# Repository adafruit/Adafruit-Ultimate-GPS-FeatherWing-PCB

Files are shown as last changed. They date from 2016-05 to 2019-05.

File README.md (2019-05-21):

## Adafruit Ultimate GPS FeatherWing PCB
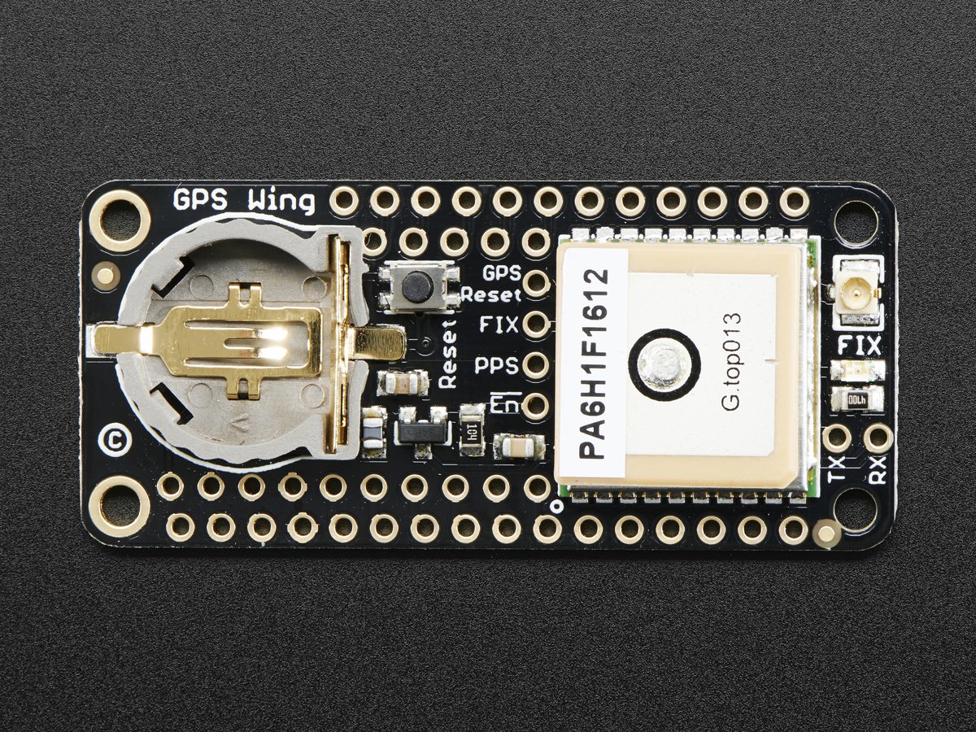
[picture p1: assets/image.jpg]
<a href="http://www.adafruit.com/products/3133"><br/>
Click here to purchase one from the Adafruit shop</a>

The Adafruit Ultimate GPS FeatherWing plugs right into your Feather board and gives it a precise, sensitive, and low power GPS module for location identifcation anywhere in the world. As a bonus, the GPS can also keep track of time once it is synced with the satellites.

Works with all Feathers except for those with USB-Serial converters that use the UART pins. Right now that means the ESP8266 Huzzah Feather and nRF52 Feather don't work

PCB files for the Adafruit Ultimate GPS FeatherWing. The format is EagleCAD schematic and board layout
- https://www.adafruit.com/products/3133

### License

Adafruit invests time and resources providing this open source design, please support Adafruit and open-source hardware by purchasing products from [Adafruit](https://www.adafruit.com)!

All text above must be included in any redistribution

Designed by Limor Fried/Ladyada for Adafruit Industries.
Creative Commons Attribution/Share-Alike, all text above must be included in any redistribution. 
See license.txt for additional information.

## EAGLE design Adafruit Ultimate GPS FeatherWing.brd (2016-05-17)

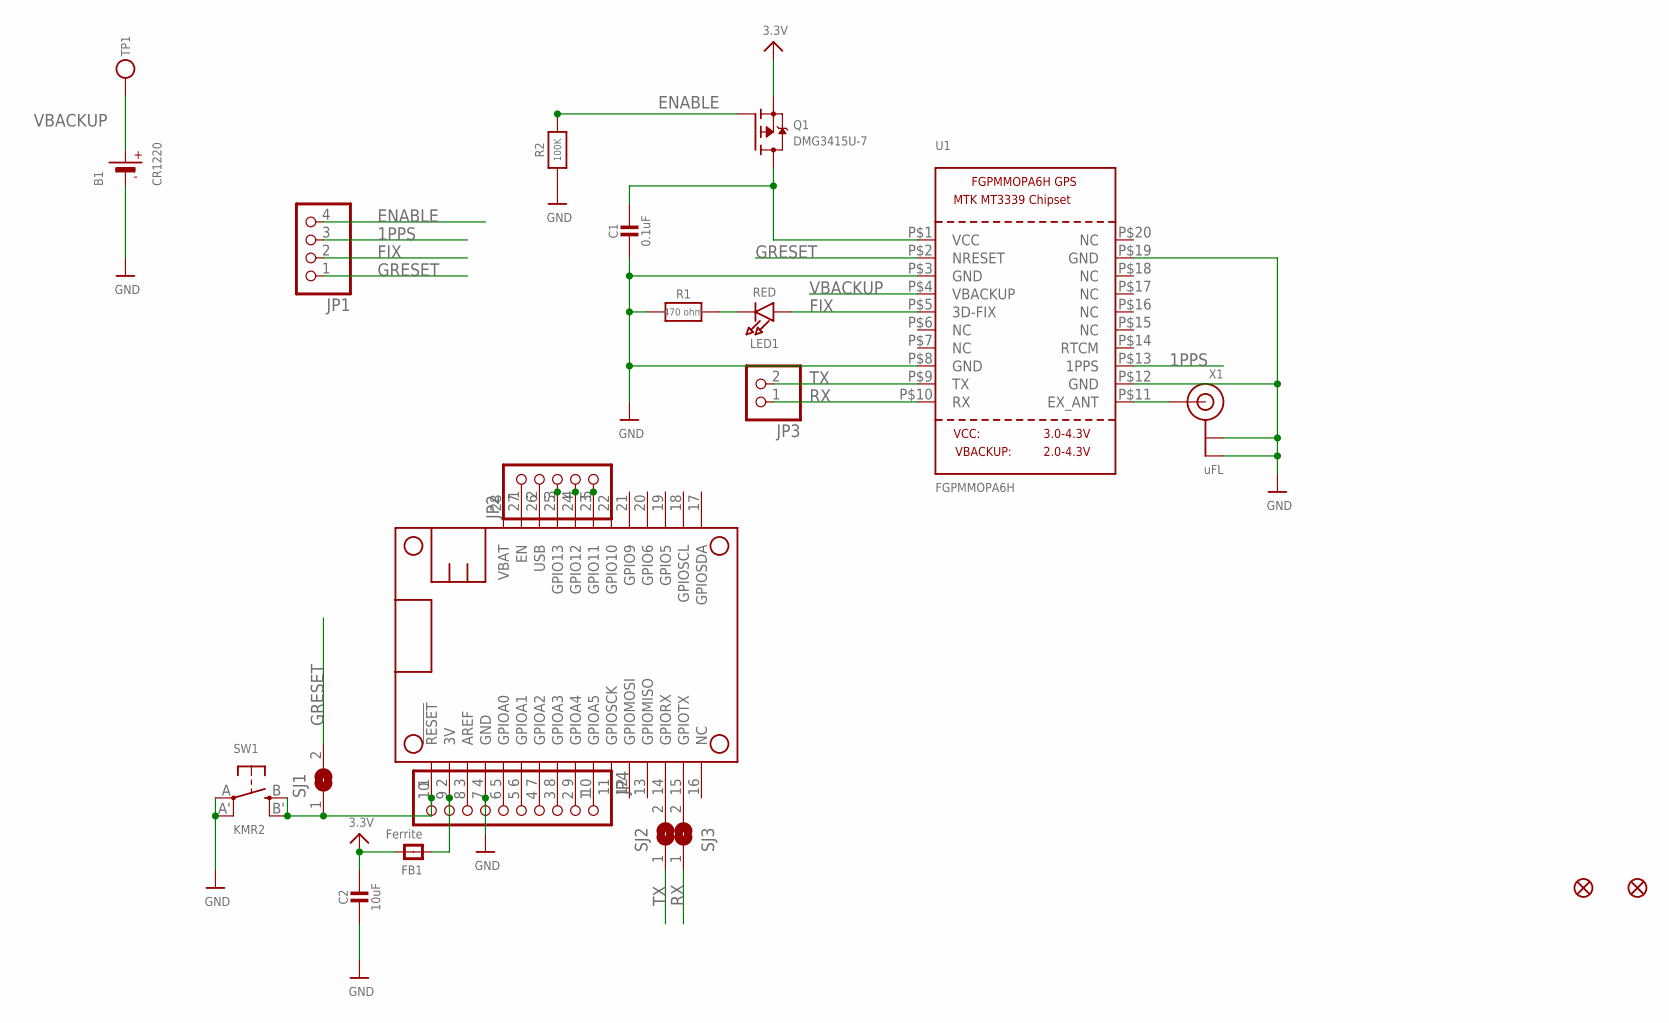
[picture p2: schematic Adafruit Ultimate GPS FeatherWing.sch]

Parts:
B1: CR1220; CR1220-2
C1: 0.1uF; 0805-NO
C2: 10uF; 0805-NO
FB1: Ferrite; 0805-NO
FID1, FID2: FIDUCIAL""; FIDUCIAL_1MM
JP1: HEADER-1X4ROUND; 1X04_ROUND
JP2: HEADER-1X570MIL; 1X05_ROUND_70
JP3: HEADER-1X2ROUND; 1X02_ROUND
JP4: HEADER-1X10ROUND; 1X10_ROUND
LED1: RED; CHIPLED_0805_NOOUTLINE
MS1: FEATHERWING
Q1: DMG3415U-7; SOT23-WIDE
R1: 470 ohm; 0805-NO
R2: 100K; 0805-NO
SJ1: SOLDERJUMPER; SOLDERJUMPER_ARROW_NOPASTE
SJ2, SJ3: SOLDERJUMPERCLOSED; SOLDERJUMPER_CLOSEDWIRE
SW1: KMR2; BTN_KMR2_4.6X2.8
TP1: TESTPOINTROUND1.5MM; TESTPOINT_ROUND_1.5MM
U1: FGPMMOPA6H
X1: uFL; U.FL

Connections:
1PPS: JP1.3, U1.P$13 (1PPS)
3.3V: C2.1, FB1.2, Q1.2 (S)
3V: FB1.1, JP4.9, MS1.2 (3V)
ENABLE: JP1.4, Q1.1 (G), R2.2
FIX: JP1.2, LED1.A, U1.P$5 (3D-FIX)
GND: B1.-, C1.2, C2.2, JP4.7, MS1.4 (GND), R1.1, R2.1, SW1.A, SW1.A' (P1), U1.P$3 (GND), U1.P$8 (GND), U1.P$12 (GND), U1.P$19 (GND), X1.1 (GND), X1.2 (GND)
GRESET: JP1.1, SJ1.2, U1.P$2 (NRESET)
unnamed: JP2.3, MS1.25 (GPIO13)
unnamed: LED1.C, R1.2
unnamed: JP2.4, MS1.24 (GPIO12)
unnamed: U1.P$11 (EX_ANT), X1.3 (SIGNAL)
unnamed: JP2.5, MS1.23 (GPIO11)
unnamed: JP4.1, MS1.10 (GPIOA5)
unnamed: JP4.2, MS1.9 (GPIOA4)
unnamed: JP4.3, MS1.8 (GPIOA3)
unnamed: JP4.4, MS1.7 (GPIOA2)
unnamed: JP4.5, MS1.6 (GPIOA1)
unnamed: JP4.6, MS1.5 (GPIOA0)
unnamed: JP4.10, MS1.1 (!RESET), SJ1.1, SW1.B (S), SW1.B' (S1)
unnamed: JP4.8, MS1.3 (AREF)
unnamed: JP2.1, MS1.27 (EN)
unnamed: C1.1, Q1.3 (D), U1.P$1 (VCC)
unnamed: MS1.14 (GPIORX), SJ2.2
unnamed: MS1.15 (GPIOTX), SJ3.2
RX: JP3.1, SJ3.1, U1.P$10 (RX)
TX: JP3.2, SJ2.1, U1.P$9 (TX)
USB: JP2.2, MS1.26 (USB)
VBACKUP: B1.+, TP1.P$1, U1.P$4 (VBACKUP)

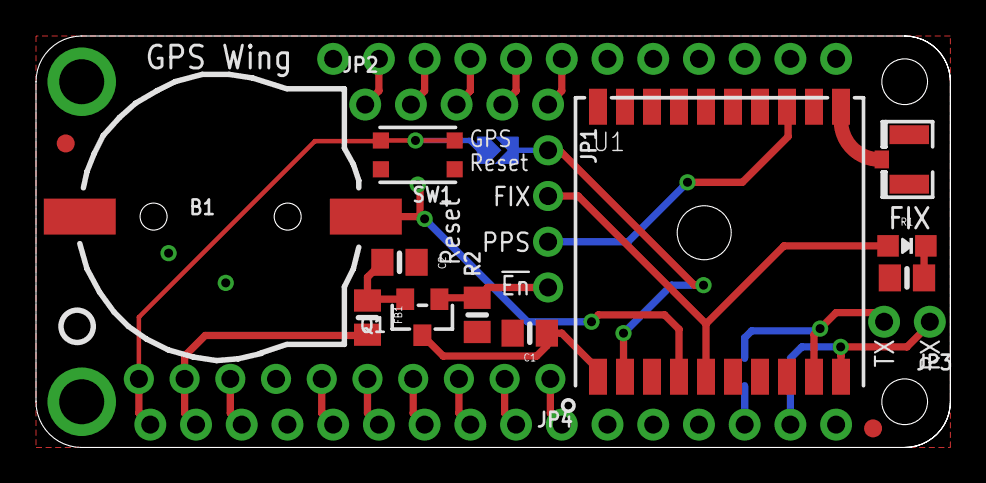
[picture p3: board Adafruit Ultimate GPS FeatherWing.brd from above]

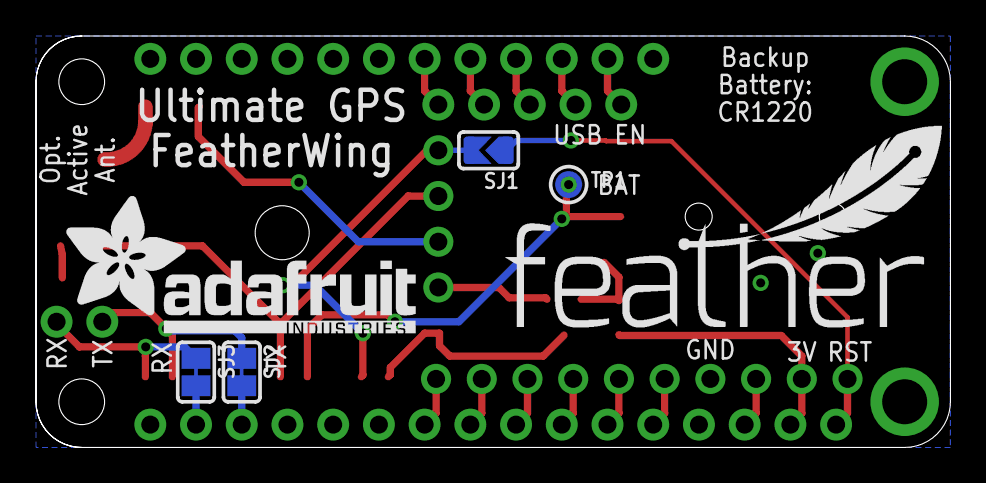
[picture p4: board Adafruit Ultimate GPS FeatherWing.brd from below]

Board: 2 copper layers, 50.8 x 22.9 mm, 25 parts (6 on the bottom side), 28 nets.

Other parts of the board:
U$9: PCBFEAT-REV-040
U$10: FEATHERLOGO
U$11: ADAFRUIT_TEXT_20MM

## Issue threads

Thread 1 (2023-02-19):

files don't open in eagle cad 9.6.2

tonysunshine, 2023-02-19:
get an error for both the board and schematic that says "This is not an EAGLE file"
